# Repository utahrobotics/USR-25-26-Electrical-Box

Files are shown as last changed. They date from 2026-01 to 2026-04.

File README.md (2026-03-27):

# About
We're going modular this year! 2025-2026 files for the Utah Students Robotics Electrical Subteam can be found here.

## Folders
### Backplane
* The mainboard used to host and connect most of our other boards
* Uses 8-bit ISA connectors

### MCU/Digital Card
* Hosts the main Raspberry Pi Pico that interfaces with a mini PC and handles digital I/O

### Motor Driver Card
* Quadruple motor drivers capable of independently driving four linear actuators

### Analog Card
* Essentially an I/O expansion board that uses a second Pi Pico to handle exclusively analog signals.

### Power Delivery Board
* Routes 24 volts to the rest of the robot and produces 12v and 5v low-current power for general use.

### Protoboard
* Perfboard with 8-bit ISA edge connectors
* For physically prototyping other board designs

### ~~Realsense Adapter~~
* ~~Adapter for Intel Realsense T265~~

### Libraries
* KiCad symbol and footprint libraries
* Make sure to use relative paths!
  * `${KIPRJMOD}/../Libraries/USR.kicad_sym` for symbols
  * `${KIPRJMOD}/../Libraries/USR.pretty` for footprints

### ~~USB 2 to 3 bridge~~
~~???~

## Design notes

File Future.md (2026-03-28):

# Future-proofing Electrical Plans SP2025
This document is intended to serve as essentially a "wishlist" of sorts regarding future organization and development of the Electrical subsystem.

## Generic GPIO blocks
-   Group blocks of generic digital/analog GPIO pins on backplane layout. These can then be allocated as needed as things progress so that at the very least, there is a known pinout to work off of.
-   This also brings the advantage of the backplane pinout becoming decoupled from specific use-cases, meaning that a single change involving the pinout of one board **will not** result in changes rippling across every other board.
    - Take advantage of KiCAD's "rule zones" features to set netclasses on otherwise generic pins

## Defined PCB size classes
-   Provide blank PCB templates using KiCAD's recently-added "design blocks" feature that allows for schematic and PCB components to be exported in blocks and be available for use between any projects that import the block library.
-   Basic "small", "medium", and "large" blocks exist as square sizes
-   Variant "small-wide", "medium-wide", and "large-wide" also exist
-   Narrow variants might not necessarily exist depending on edge connector choice
    -   To address this, multiple different edge connector types may also be made available for use within the libraries for greater flexibility

## Reusable design blocks
-   Building off of the design blocks that will be utilized for PCB templates, complete component design blocks (matched schematic and PCB layout blocks in pairs) may also be added with unique identifiers that provide an at-a-glance description of functionality (for example, voltage conversion)
-   This alongside custom schematic symbols footprints may be very useful
-   If it comes to it, the logical extension of this would be for the design blocks to literally exist as mini-PCBs that can be independently added to a design either explicitly (plugs into headers/is soldered onto the rest of the board like a sort of PCB "patch") or implicitly (integrated into the rest of the design without the need for soldering)
-   As decisions are made down the line in other subteams, design blocks can then be quickly swapped in and out
    -   If possible, lining up the input and output lines on both the schematic block and PCB layout block would make such swapping of components effectively seamless regarding routing. Likely would be overkill to do this though, and simply having it be labeled as a specific design block region may be enough.
-   This follows the trend that has occurred across the team with increasingly modular designs as well, and overall should hopefully result in much greater flexibility that reduces the team's reliance on decisions being made by other teams.

## Make criticial decisions first and foremost and *stick with it*
-   The assumption of the electrical subsystem existing in a vacuum and thus capable of designating for itself as much space as desired is only made in the earliest stages of prototyping when designs and functionality are being tested.
-   Design for as compact of a PCB layout as possible. Routing-wise, this may mean it becomes necessary to rely on sub-PCBs to make a pseudo-4 layer board in a "PCB sandwich" style build.
-   "Large" and "Large wide" boards especially are discouraged from being used as part of the final design
-   Designing for the minimal space use makes electrical box placement much more flexible, but the minimum size *must* be enforced on other sub-teams in their designs. If we say that we cannot go below a certain size, drill it into the other teams such as Mechanical so that they know that that is a **hard limit** that cannot be passed. 
    -   No space for an already minimum-size electrical box? No robot.
    -   TL;DR: Electrical sub-team cannot continue to exist in a "reactionary" state where it designs based exclusively on the decisions of other sub-teams.

## Designate "Design Mentor" role(s) within the subteam
-   These roles exist to guide and approve of designs prior to protototyping and production. Ideally, they should have some degree of expertise in the field they mentor in.
    -   For example: A hypothetical **Layout Mentor** role has longtime experience in schematic and PCB layout. They should work with team leads (or perhaps they *are* one of the leads) to produce a **design guidelines** document. This establishes what should be taken into consideration in a given design, and suggested values for aspects such as trace width.
-   Closer to the competition when designs for the final PCBs are being laid out, these mentors will work directly with those doing the designing to ensure that the PCB designs will, in simple terms, "work". They should look for obvious mistakes that may compromise a robot's ability to function or cause harm to other parts of the design, and assist in the redesigning process if need be.

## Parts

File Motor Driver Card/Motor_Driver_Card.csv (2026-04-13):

Reference | Qty | Value | DNP | Exclude from BOM | Exclude from Board | Footprint | Datasheet
D1,D4,D7,D10 | 4 | LED |  |  |  | LED_THT:LED_D3.0mm
D2,D5,D8,D11 | 4 | Red |  |  |  | LED_THT:LED_D3.0mm
D3,D6,D9,D12 | 4 | Green |  |  |  | LED_THT:LED_D3.0mm
J1 | 1 |  |  |  |  | USR:BUS_XT
J2,J3,J4,J5 | 4 | JST |  |  |  | Connector_PinHeader_2.54mm:PinHeader_1x02_P2.54mm_Vertical
M1,M2,M3,M4 | 4 | MD13B |  |  |  | USR:MD31B | https://www.pololu.com/product/2995
Q1,Q2,Q3,Q4 | 4 | 2N3904 |  |  |  | Package_TO_SOT_THT:TO-92_Inline | https://www.onsemi.com/pub/Collateral/2N3903-D.PDF
R1,R4,R5,R8,R9,R12,R13,R16 | 8 | 5K1 |  |  |  | Resistor_THT:R_Axial_DIN0207_L6.3mm_D2.5mm_P10.16mm_Horizontal
R2,R3,R6,R7,R10,R11,R14,R15 | 8 | 510R |  |  |  | Resistor_THT:R_Axial_DIN0207_L6.3mm_D2.5mm_P10.16mm_Horizontal
TH1,TH2,TH3,TH4 | 4 | Thermistor_US |  |  |  | Resistor_THT:R_Axial_DIN0204_L3.6mm_D1.6mm_P2.54mm_Vertical

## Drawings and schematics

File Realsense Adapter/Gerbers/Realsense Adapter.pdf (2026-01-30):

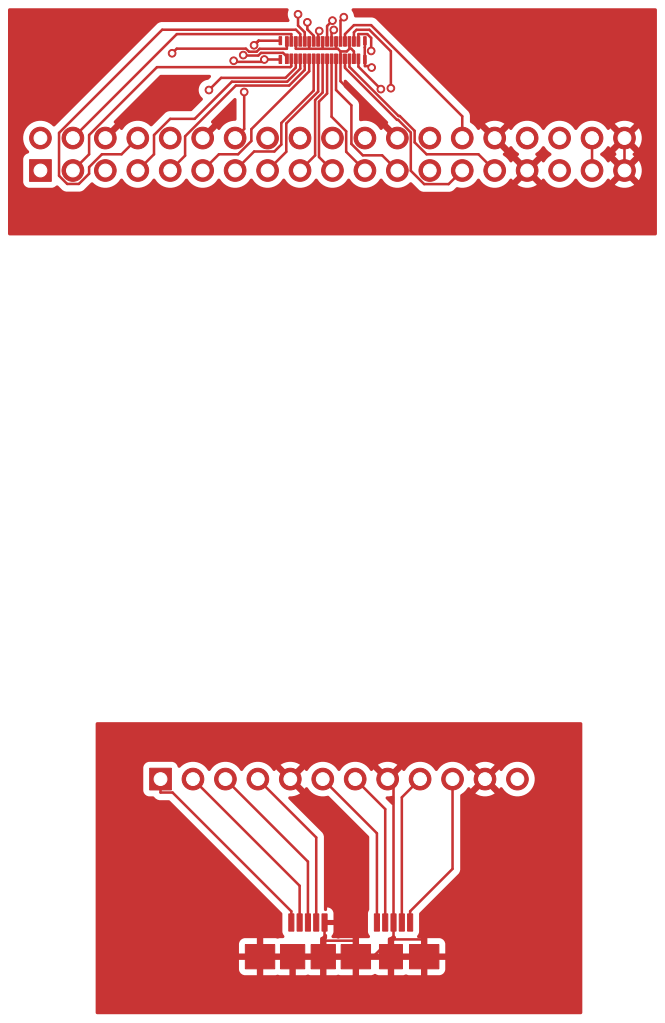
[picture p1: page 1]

Id: 1/9 Title: Intel Realsense Breakout Board

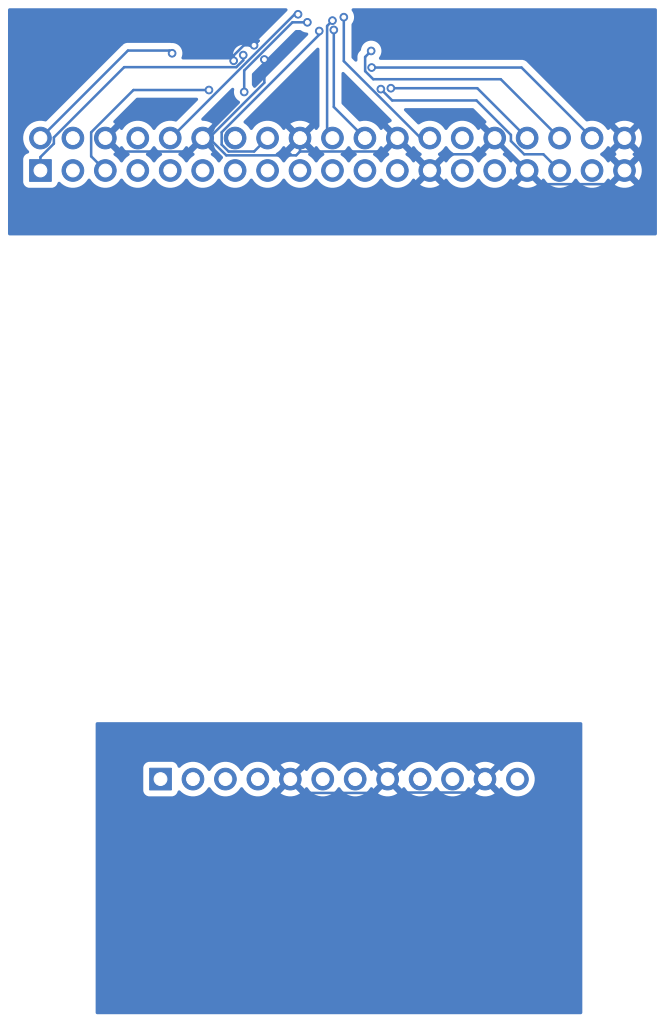
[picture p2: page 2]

Id: 2/9 Title: Intel Realsense Breakout Board

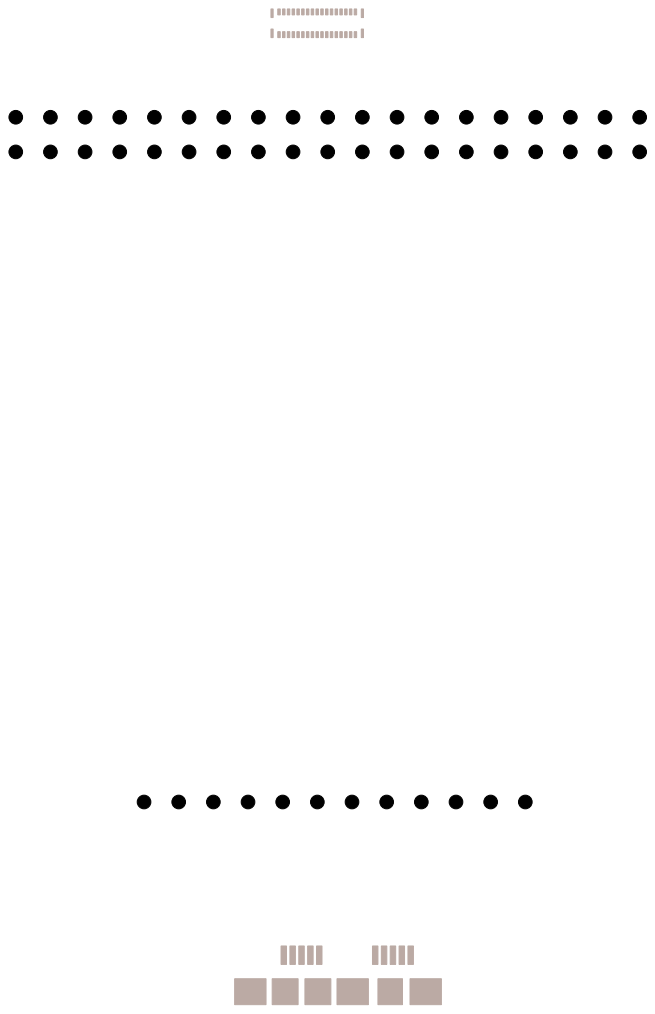
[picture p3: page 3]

Id: 3/9 Title: Intel Realsense Breakout Board

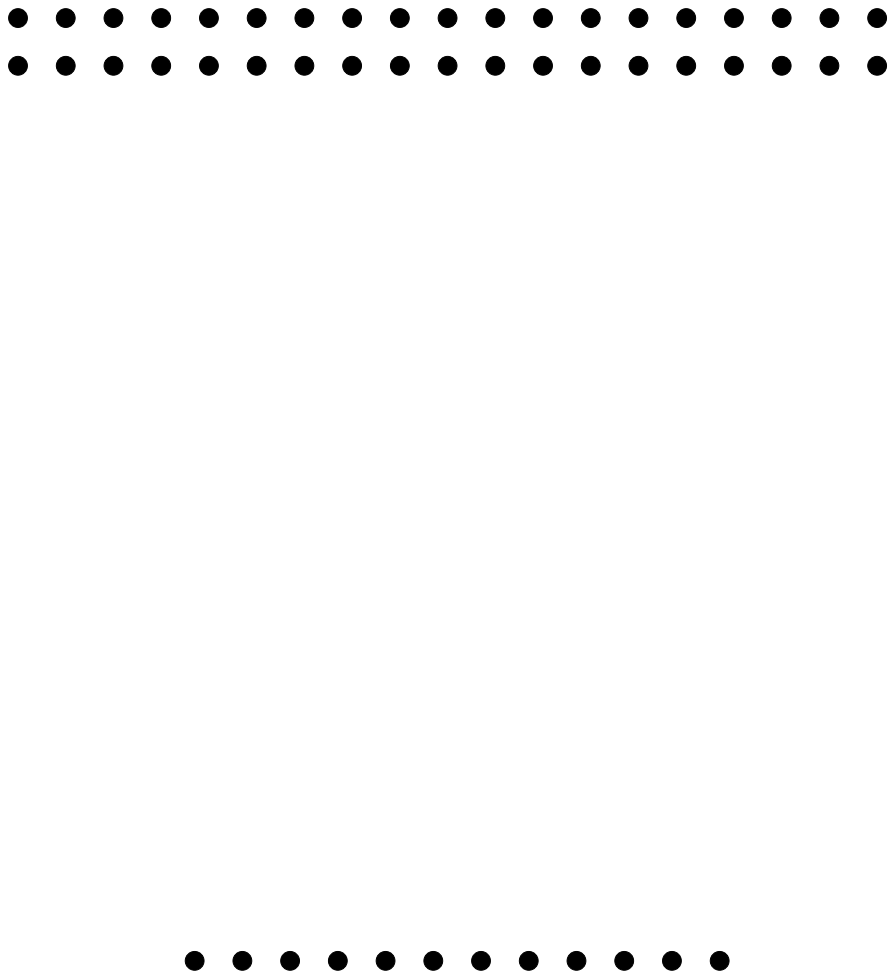
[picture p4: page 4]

Id: 4/9 Title: Intel Realsense Breakout Board

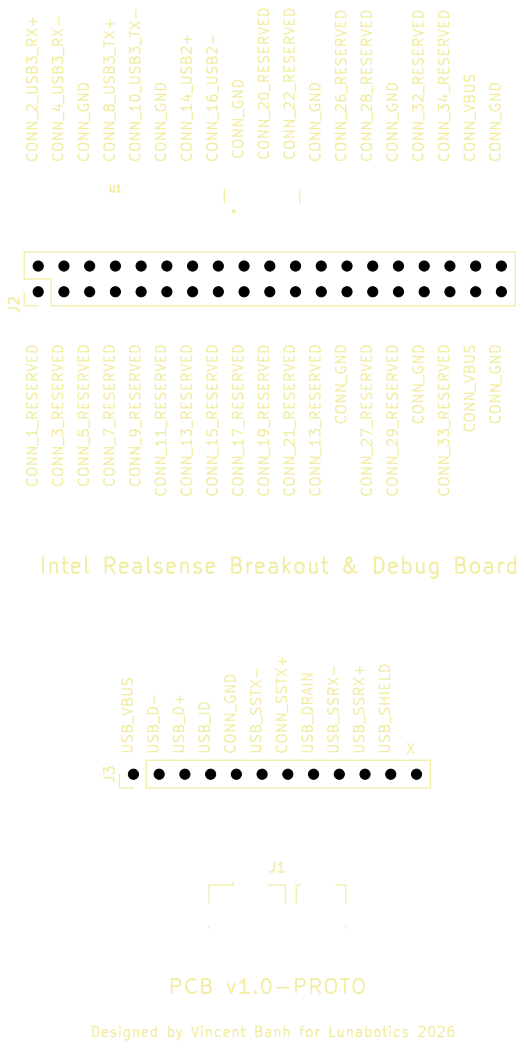
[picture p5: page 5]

Id: 5/9 Title: Intel Realsense Breakout Board

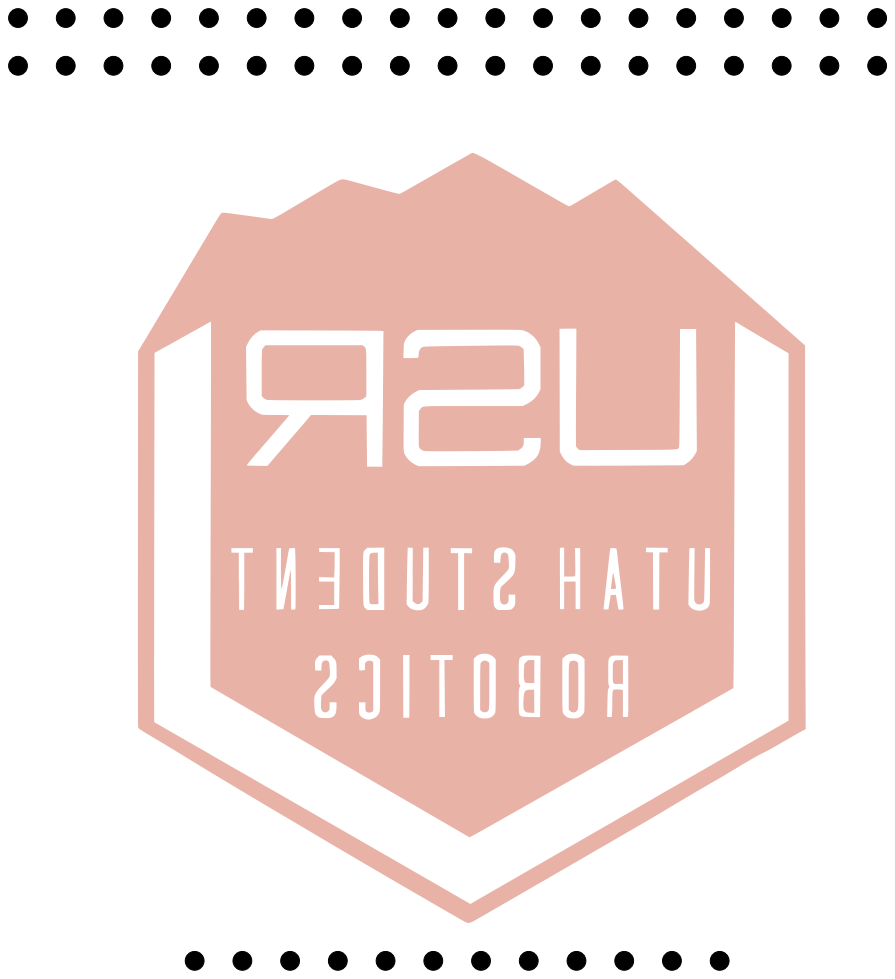
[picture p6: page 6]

Id: 6/9 Title: Intel Realsense Breakout Board

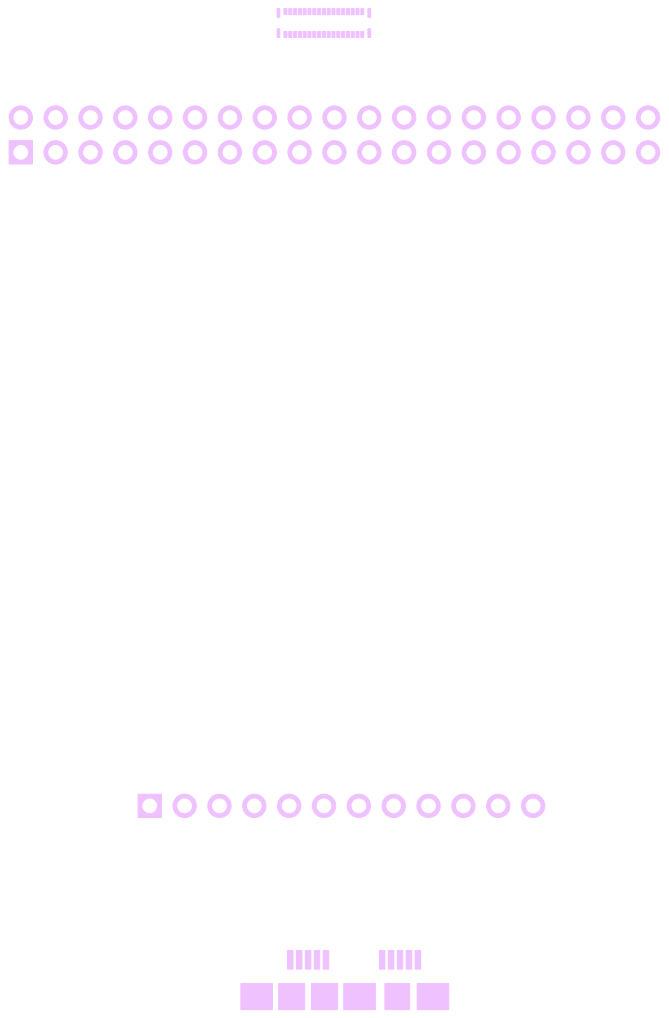
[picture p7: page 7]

Id: 7/9 Title: Intel Realsense Breakout Board

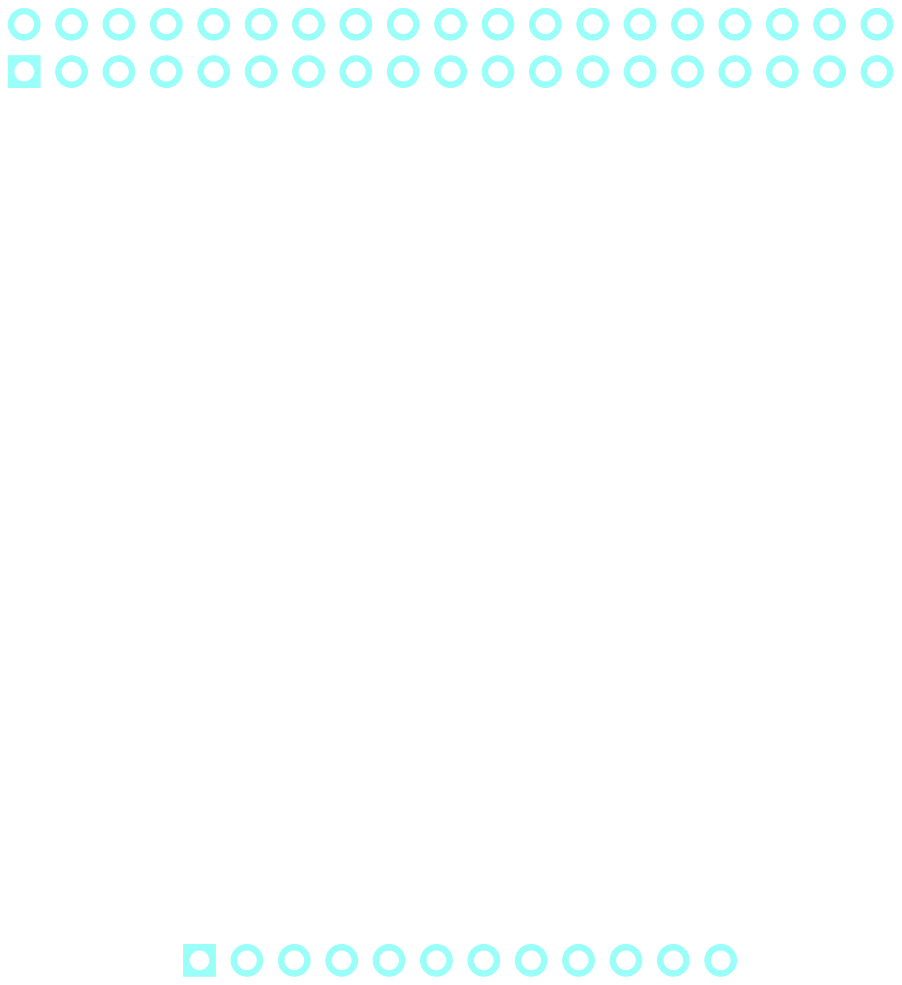
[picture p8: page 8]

Id: 8/9 Title: Intel Realsense Breakout Board

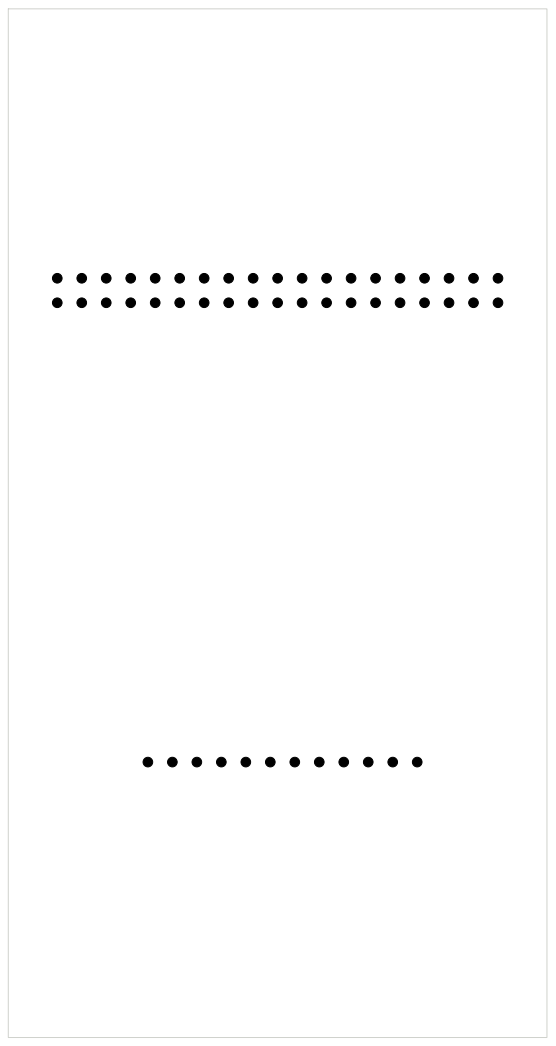
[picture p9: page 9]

Id: 9/9 Title: Intel Realsense Breakout Board

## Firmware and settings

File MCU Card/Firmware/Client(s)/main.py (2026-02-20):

from machine import UART, Pin
import utime

# 9600 baud, UART0, GP16 (TX), GP17 (RX)
uart = machine.UART(0, baudrate=9600, tx=16, rx=17);
led = machine.Pin("LED", machine.Pin.OUT)

# simple test: receive LED toggle commands. replace "DEV1" with whichever device identifier you wish to use.
while True:    
    if uart.any():
        received_data = uart.read().decode('utf-8')
        split_data = received_data.split(',')
        print("Received: ", split_data)
        if (split_data[0] == "DEV1"):
            print("Device selected with DEV1.")
            uart.write("DEV1 RESPONSE: " + str(utime.time()))
            if (split_data[1] == "LEDTOGGLE"):
                led.toggle()

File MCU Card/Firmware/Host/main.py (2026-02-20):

from machine import UART, Pin, Timer
import utime, time

# Interrupt handler to ensure that we service ANY incoming UART data ASAP.
# This interrupt with its multiple calls to string functions takes about 31 ticks to complete, meaning that
# if data arrives faster than that, the UART handler will starve the rest of the microcontroller to the point
# of stalling.
def uart_handler(int):
    global time_dev1, time_dev2
    inttime = time.ticks_ms()
    received_data = uart.read().decode('utf-8')
    if(received_data[0:4] == "DEV1"):        
        print("Received: {", received_data, "} from DEV1 in", time.ticks_diff(inttime, time_dev1), "ms")
    print("Interrupt completed in", time.ticks_diff(time.ticks_ms(), inttime), "ticks")

# 9600 baud, UART0, GP16 (TX), GP17 (RX)
uart = machine.UART(0, baudrate=9600, tx=16, rx=17);
uart.irq(handler=uart_handler, trigger=UART.IRQ_RXIDLE, hard=0)

# Basic while loop handles polling
while True:
    utime.sleep_ms(10)
    time_dev1 = time.ticks_ms()
    uart.write("DEV1,LEDTOGGLE")
    #print("Polling DEV1")
    utime.sleep_ms(20)
    time_dev2 = time.ticks_ms()
    uart.write("DEV2")
    #print("Polling DEV2")
    utime.sleep_ms(15)		#this must be 13 or higher to avoid the uart handler triggering twice. Ideally 15.

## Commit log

2025-07-09 Added a readme to the repository, first test of pushing directly from KiCAD.
    [USR 25-26 Electrical Box.kicad_pcb]
2025-07-18 Added indicator LEDs for power and 4 configurable status LEDs to the MCU host board. Waiting on a decision regarding placement of 3-to-8 and 2-to-4 decoder chips.
    [MCU_host.kicad_sch, USR 25-26 Electrical Box.kicad_sch]
2025-07-18 Staged initial slot connections for backplane. May need to separate individual boards into separate projects.
    [BOM-USR 25-26 Electrical Box.csv, MCU_host.kicad_sch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]
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2025-08-01 Begin work on PCB layout
    PCB layout for both the bus board and the MCU card have begun.
    [USR 25-26 Electrical Box.kicad_sch, USR 25-26 MCU Card.kicad_pcb, USR 25-26 MCU Card.kicad_sch]
2025-08-01 forgot to save a thing whoops
    [USR 25-26 MCU Card.kicad_sch]
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2025-08-11 Laid out revision 0 PCB for backplane.
    [USR 25-26 Electrical Box.kicad_pcb, USR 25-26 Electrical Box.kicad_sch]
2026-01-20 Add universal USR protoboard
    [Backplane-B_Cu.gbr, Backplane-B_Mask.gbr, Backplane-B_Paste.gbr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]
2026-01-20 Added title block to PCB layout
    [Backplane.kicad_pcb]
2026-01-24 Very VERY rough Realsense adapter PCB
    Zero guarantee that this works. It might fry a realsense for all I know.
    [Realsense Adapter.kicad_pcb, Realsense Adapter.kicad_sch]
2026-01-30 Version v1.0-PROTO of Realsense adapter complete
    [Realsense Adapter-B_Cu.gbr, Realsense Adapter-B_Mask.gbr, Realsense Adapter-B_Paste.gbr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]
2026-02-02 Minor updates to plotting settings
    [Realsense Adapter.kicad_pcb]
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2026-02-27 Reformated the PDB folder
    [USR-PDB.kicad_pcb, USR-PDB.kicad_sch]
2026-02-27 Added datasheets and associated footprints to symbols
    [USR-PDB.kicad_sch]
2026-02-27 PDB: added footprint for D2
    [USR-PDB.kicad_pcb, USR-PDB.kicad_sch]
2026-02-27 Added footprints and datasheets for capacitors, inductors, and diodes
    [USR-PDB.kicad_pcb, USR-PDB.kicad_sch]
2026-02-27 Add layout of motor driver card
    [Driver.kicad_sch, Motor_Driver_Card.kicad_pcb, Motor_Driver_Card.kicad_sch]
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2026-03-03 Added dimensions to protoboard for reference as base backplane size
    [Backplane.kicad_pcb]
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2026-03-06 added SYM & footprint for JST connectors, added comments to PDB schem
    [USR-PDB.kicad_pcb, USR-PDB.kicad_sch]
2026-03-06 Added Backplane revision 1 PCB and updated footprints for card edge and slot connector
    [Backplane.kicad_pcb, Backplane.kicad_sch]
2026-03-06 Added some dimensioning to the backplane and generated gerbers for production
    [Backplane.kicad_pcb]
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2026-03-12 Added footprints for vertical and horizontal XT-90 connectors alongside updating backplane PCB
    [Backplane.kicad_pcb, Backplane.kicad_sch]
2026-03-12 traces added for the power delivery boards PCB
    [USR-PDB.kicad_pcb, USR-PDB.kicad_sch]
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2026-03-16 Updated Analog Board schem, added comments and pico symbol
    [USR-AB.kicad_sch]
2026-03-16 Added dimension marks to backplane. Prepare to create backplane card support frame.
    [Backplane.kicad_pcb]
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2026-03-20 Changed JST connectors in the power delivery board's PCB to be RA JST connectors
    [USR-PDB.kicad_pcb]
2026-03-20 fixed typo on PDB schematic
    [USR-PDB.kicad_sch]
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2026-03-21 Apply new backplane pinouts to motor driver card
    [Motor_Driver_Card.kicad_pcb, Motor_Driver_Card.kicad_sch]
2026-03-22 added silkscreen logo and labeling to motor driver card
    Still needs thermistors added
    [Motor_Driver_Card.kicad_pcb]
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2026-03-22 Updated MCU card and PDB
    MCU card schematic is laid out (tentative but likely final)
    PDB has had minor trace width updates
    [USR 25-26 MCU Card.kicad_sch, USR-PDB.kicad_pcb]
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2026-03-24 Changed 2025 to 2026 on motor driver silkscreen. Motor driver card is now considered complete.
    [Motor_Driver_Card.kicad_pcb]
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2026-03-25 Fixed trace errors on MCU board
    [USR 25-26 MCU Card.kicad_pcb]
2026-03-25 fixed trace sizes for MCU board
    [USR 25-26 MCU Card.kicad_pcb]
2026-03-26 [Analog Board] added power to PICO, updated board dimensions
    [USR-AB.kicad_pcb, USR-AB.kicad_sch]
2026-03-26 Added board dimension info onto the PCB, updated silkscreen
    [USR-AB.kicad_pcb]
2026-03-26 Added 3D model for the slot connector for 3D rendering
    [Backplane.kicad_pcb]
2026-03-26 added silkscreen labels to ports on analog board
    [USR-AB.kicad_pcb]
2026-03-26 replaced LM2575 volt. regulator with 2x LM7805 in parallel
    [USR-PDB.kicad_pcb, USR-PDB.kicad_sch]
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2026-03-26 Finalized designs for MCU card, Analog board, and MDCB
    Added additional vias to all in order to minimize ground loops and stitch together front and back ground planes.
    [Motor_Driver_Card.kicad_pcb, USR 25-26 MCU Card.kicad_pcb, USR-AB.kicad_pcb]
2026-03-26 Added vias to PDB to stitch together front and back ground planes
    [USR-PDB.kicad_pcb]
2026-03-27 Last-minute changes for pico GPIO voltage levels
    Adjusted MDCB to work in 3.3v rather than 5v to not blow up a pico. Thankfully we have a readily available 3.3v source from the motor drivers themselves.
    [Driver.kicad_sch, Motor_Driver_Card.kicad_pcb, Motor_Driver_Card.kicad_sch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]
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2026-03-28 Complete redesign of PDB pcb
    AAAAAAAAAAAAAAAAAAAAAAAAAAAAAAAAAAAAAAAAAAAA
    [Motor_Driver_Card.kicad_pcb, USR-PDB.kicad_pcb, USR-PDB.kicad_sch]
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2026-04-05 Add files via upload
    this is step file for the 21700 2p7s battery holder (with additional changes for cell tolerance)
2026-04-13 Updated PCB designs across the motor driver, analog board, and PDB
    [Driver.kicad_sch, Motor_Driver_Card.csv, Motor_Driver_Card.kicad_pcb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]
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2026-04-19 PDB that doesn't have the Hall Effect sensors
    [PDB_noHE.kicad_pcb, PDB_noHE.kicad_sch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]
